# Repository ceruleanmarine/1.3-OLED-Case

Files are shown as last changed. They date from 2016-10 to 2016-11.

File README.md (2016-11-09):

#Waterproof case for COTS 1.3" OLED modules

<p align="center">
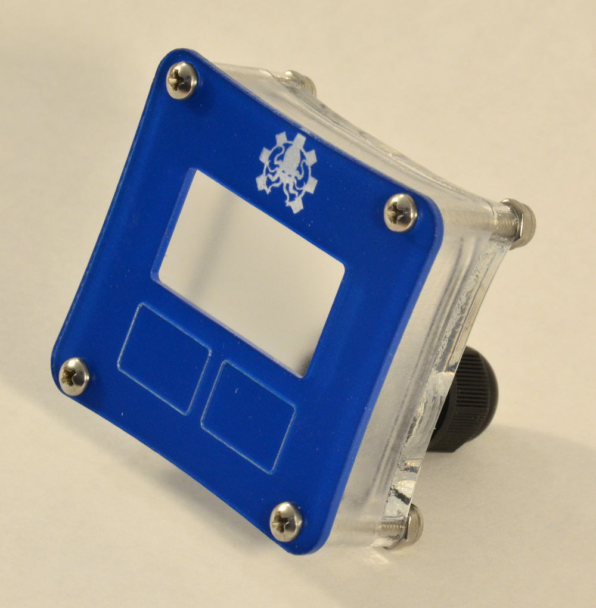
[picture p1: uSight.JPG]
  
</p>

##Summary:

The case utilizes acrylic layers to create the enclosure and the seal is provided via an o-ring. The internal is easily accessible via a bolt-on back cover and a cable feedthru is provided by a PG7 cable gland. The internal volume is large enough for the display and a small mcu board (pro mini, teensy, esp, etc) and control can be provided by capacitive sensing (untested) through the front bezel plate. Additional layers can be stacked on to increase the internal volume as required.

##Features:

- CNC cut acrylic
- O-ring seal for fast, simple and reliable sealing
- Engraved front panel allows for capacitive touch input
- Non-glare clear acrylic window
- Stainless hardware
- Sized to fit Arduino Pro Mini, Teensy, ESP8266, etc
- Internal dims (excluding OLED): 1.45"x1.45"x0.47"
- External dims (excluding gland): 2.25"x2.05"x0.74"

##Bill of materials:

- Body:  1/2" (12mm) acrylic
- Lens:  1/16" (1.5mm) clear acrylic for lens
- Back Cover:  1/4" (6mm) acrylic, transparent recommended
- Bezel:  1/16" (1.5mm) acrylic
- Oring, 2-032
- PG7 cable gland or other electrical penetrator
- #4-40x1" bolts, 4ea
- #4-40 nyloc nuts, 4ea
- #4 washers, 8ea

##Tools and consumables
- Scigrip 16 or weld-on #4 acrylic adhesive
- O-ring lube:  Super Lube or equivalent
- 1/2"-20 tap

##Assembly:

- Cut acrylic components
- Glue lens onto body ensuring complete coverage
- Thread hole in back cover with 1/2-20 tap for PG7
- Optional: trim PG7 to minimize threads protruding into case

##Sealing the unit:

- Clean and inspect the o-ring groove ensuring no debris is trapped inside
- Clean and inspect the sealing surface on the inside of the back cover
- Lightly lubricate the o-ring
- Install o-ring and back cover
- Inspect the o-ring seal compression.  Look for a prominent black line (see photo below) where the o-ring is compressed against the back cover.

<p align="center">
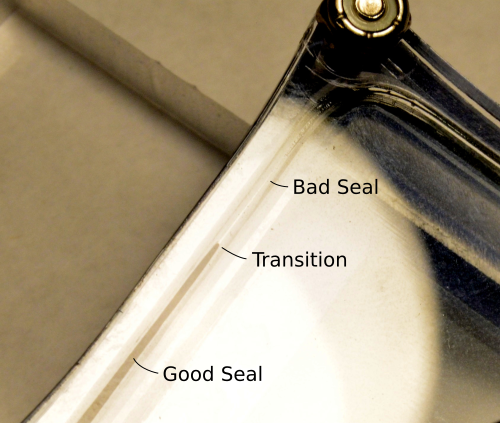
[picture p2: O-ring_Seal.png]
  
</p>

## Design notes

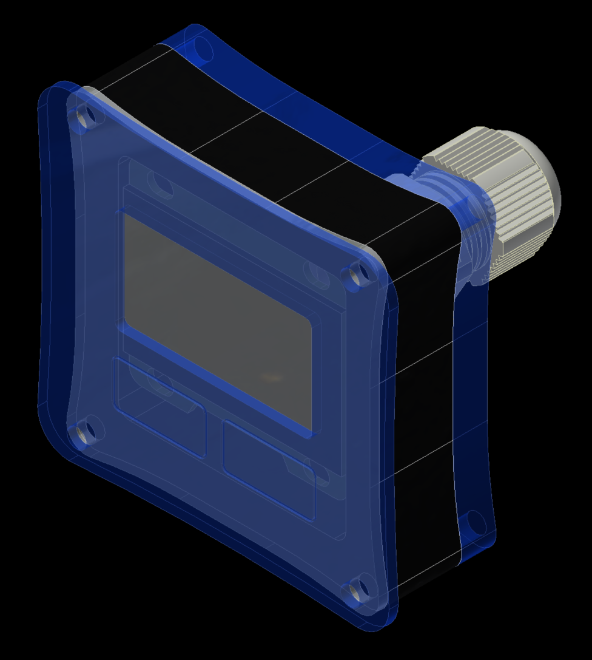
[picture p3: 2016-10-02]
Solid_Model.png

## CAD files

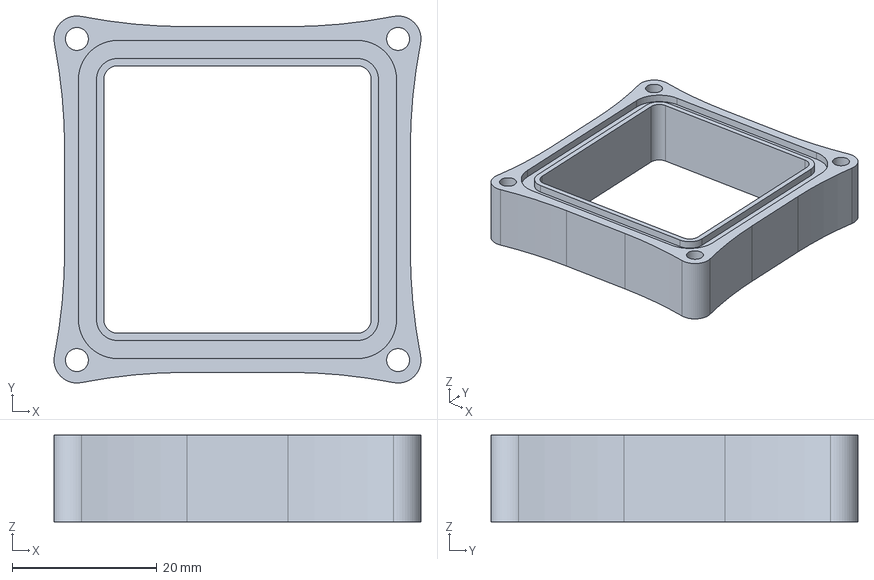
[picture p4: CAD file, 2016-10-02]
Body.igs
50.8 x 50.8 x 12.0 mm

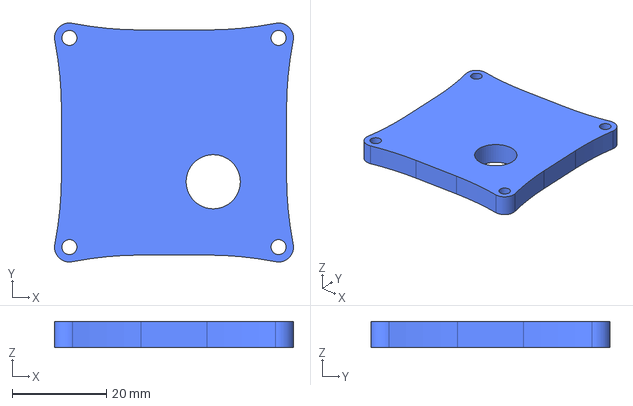
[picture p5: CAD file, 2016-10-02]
BackCover.igs
50.8 x 50.8 x 5.59 mm

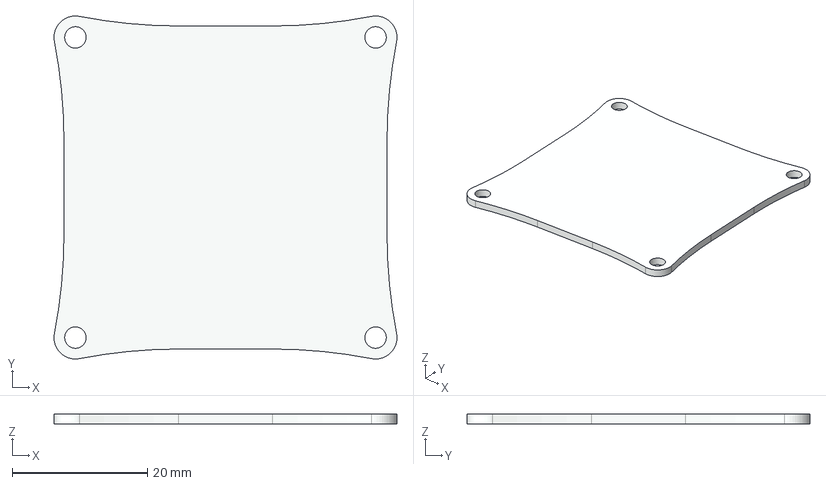
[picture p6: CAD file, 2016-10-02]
Lens.igs
50.8 x 50.8 x 1.52 mm

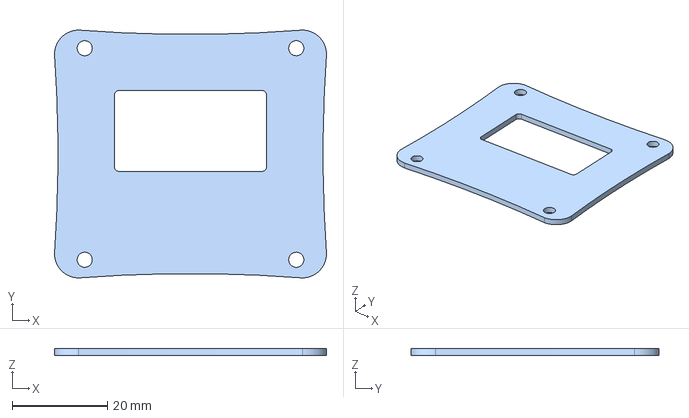
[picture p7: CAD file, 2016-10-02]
FrontCover.igs
57.1 x 52.1 x 1.52 mm
